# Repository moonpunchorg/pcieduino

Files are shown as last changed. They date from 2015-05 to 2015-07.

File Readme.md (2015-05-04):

PCIeDuino
=========

Arduino on a mini-PCIe express card.

Based design from Arduino and [SparkFun's Pro Micro 3.3V][promicro] board.

License
=======

To follow the licensing of the original Arduino modules,
all of this is shared under [CC BY-SA 3.0][cc] 2014 Moonpunch.org

[promicro]: https://www.sparkfun.com/products/12587 "Pro Micro - 3.3V/8MHz"
[cc]: https://creativecommons.org/licenses/by-sa/3.0/ "Creative Commons Attribution Share-Alike"

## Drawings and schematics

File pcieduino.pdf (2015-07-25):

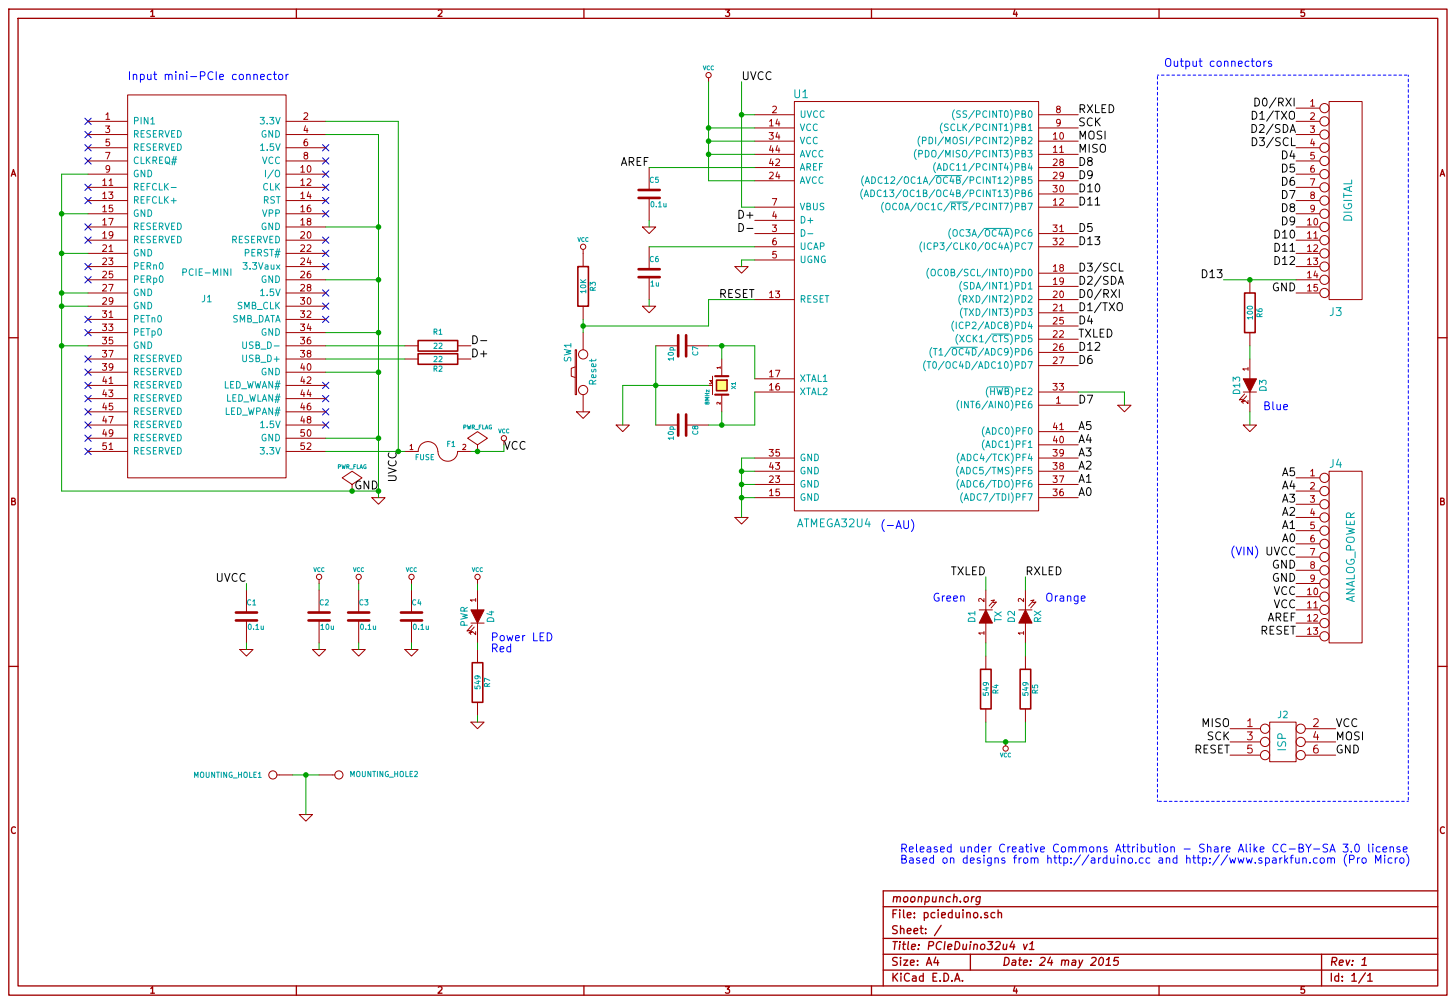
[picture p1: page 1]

Input mini-PCIe connector

Released under Creative Commons Attribution - Share Alike CC-BY-SA 3.0 license
Based on designs from http://arduino.cc and http://www.sparkfun.com (Pro Micro)

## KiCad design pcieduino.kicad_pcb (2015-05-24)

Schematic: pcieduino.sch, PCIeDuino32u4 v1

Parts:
C1, C3, C4, C5: 0.1u; SM0603_Capa; MouserPN 581-060316C104K
C2: 10u; Mouser PN 581-0805YD106K
C6: 1u; SM0603_Capa; MouserPN 581-0603YC105KAT2A
C7, C8: 10p; SM0603_Capa; MouserPN 581-06035A100J
D1: TX; LED-0603
D2: RX; LED-0603; MouserPN 720-LOL29KH2L124Z
D3: D13; LED-0603
D4: PWR; LED-0603; MouserPN 720-LSL29K-G1H2-1-Z
F1: FUSE; MouserPN 576-1206L110THYR
J1: PCIE-MINI; MODULE
J2: ISP
J3: DIGITAL
J4: ANALOG_POWER
MOUNTING_HOLE1, MOUNTING_HOLE2: CONN_1
R1, R2: 22; SM0603_Resistor; MouserPN 71-CRCW0603-22-E3
R3: 10K; SM0603_Resistor; MouserPN 71-CRCW0603-10K-E3
R4, R5, R7: 549; SM0603_Resistor; MouserPN 71-CRCW0603-549-E3
R6: 100; SM0603_Resistor; MouserPN 71-CRCW0603-100-E3
SW1: Reset; MouserPN 612-TL3313AF100QG
U1: ATMEGA32U4; TQFP44; MouserP# 556-ATMEGA32U4-AU
X1: 8MHz; SMDXTAL_50x32; MouserPN 815-ABM3B-8.0-10-1UT

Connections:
/A0: J4.6, U1.36
/A1: J4.5, U1.37
/A2: J4.4, U1.38
/A3: J4.3, U1.39
/A4: J4.2, U1.40
/A5: J4.1, U1.41
/AREF: C5.1, J4.12, U1.42
/D0/RXI: J3.1, U1.20
/D1/TXO: J3.2, U1.21
/D2/SDA: J3.3, U1.19
/D3/SCL: J3.4, U1.18
/D4: J3.5, U1.25
/D5: J3.6, U1.31
/D6: J3.7, U1.27
/D7: J3.8, U1.1
/D8: J3.9, U1.28
/D9: J3.10, U1.29
/D10: J3.11, U1.30
/D11: J3.12, U1.12
/D12: J3.13, U1.26
/D13: J3.14, R6.1, U1.32
/D+: R2.1, U1.4
/D-: R1.1, U1.3
/MISO: J2.1, U1.11
/MOSI: J2.4, U1.10
/RESET: J2.5, J4.13, R3.2, SW1.2, U1.13
/RXLED: D2.2 (K), U1.8
/SCK: J2.3, U1.9
/TXLED: D1.2 (K), U1.22
/UVCC: C1.1, F1.1, J1.2 (3.3V), J1.52 (3.3V), J4.7, U1.2, U1.7
GND: C1.2, C2.2, C3.2, C4.2, C5.2, C6.2, C7.2, C8.2, D3.2 (K), J1.4 (GND), J1.9 (GND), J1.15 (GND), J1.18 (GND), J1.21 (GND), J1.26 (GND), J1.27 (GND), J1.29 (GND), J1.34 (GND), J1.35 (GND), J1.40 (GND), J1.50 (GND), J2.6, J3.15, J4.8, J4.9, MOUNTING_HOLE1.1, MOUNTING_HOLE2.1, R7.2, SW1.1, U1.5, U1.15, U1.23, U1.33, U1.35, U1.43, X1.3 (case)
unnamed: J1.36 (USB_D-), R1.2
unnamed: J1.38 (USB_D+), R2.2
unnamed: C6.1, U1.6
unnamed: D4.2 (K), R7.1
unnamed: C8.1, U1.16, X1.2
unnamed: C7.1, U1.17, X1.1
unnamed: D3.1 (A), R6.2
unnamed: D1.1 (A), R4.1
unnamed: D2.1 (A), R5.1
VCC: C2.1, C3.1, C4.1, D4.1 (A), F1.2, J2.2, J4.10, J4.11, R3.1, R4.2, R5.2, U1.14, U1.24, U1.34, U1.44

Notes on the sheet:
Released under Creative Commons Attribution - Share Alike CC-BY-SA 3.0 license Based on designs from http://arduino.cc and http://www.sparkfun.com (Pro Micro)
Output connectors
Input mini-PCIe connector
Power LED Red
(VIN)
Green
Orange
Blue
(-AU)

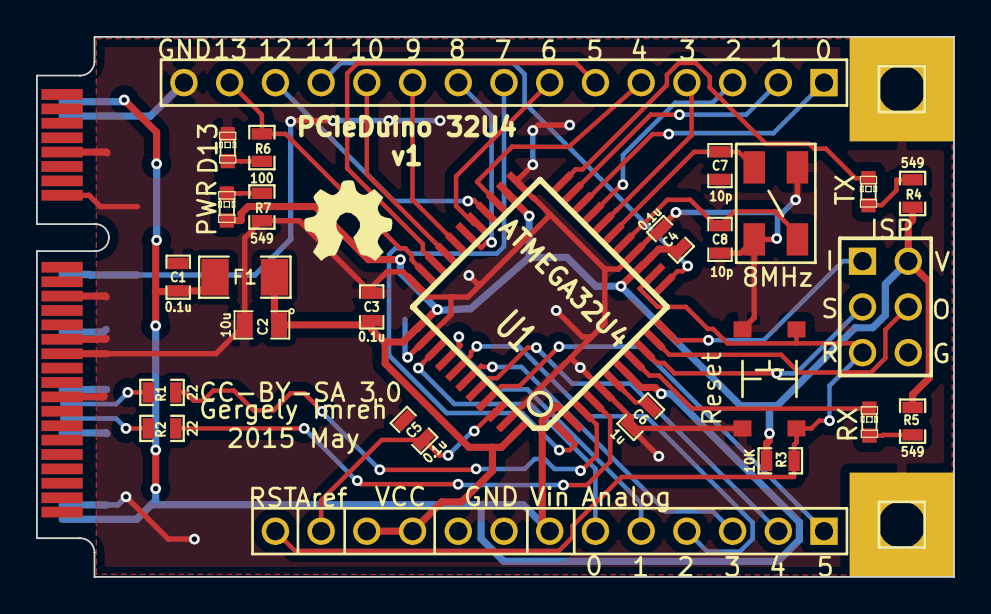
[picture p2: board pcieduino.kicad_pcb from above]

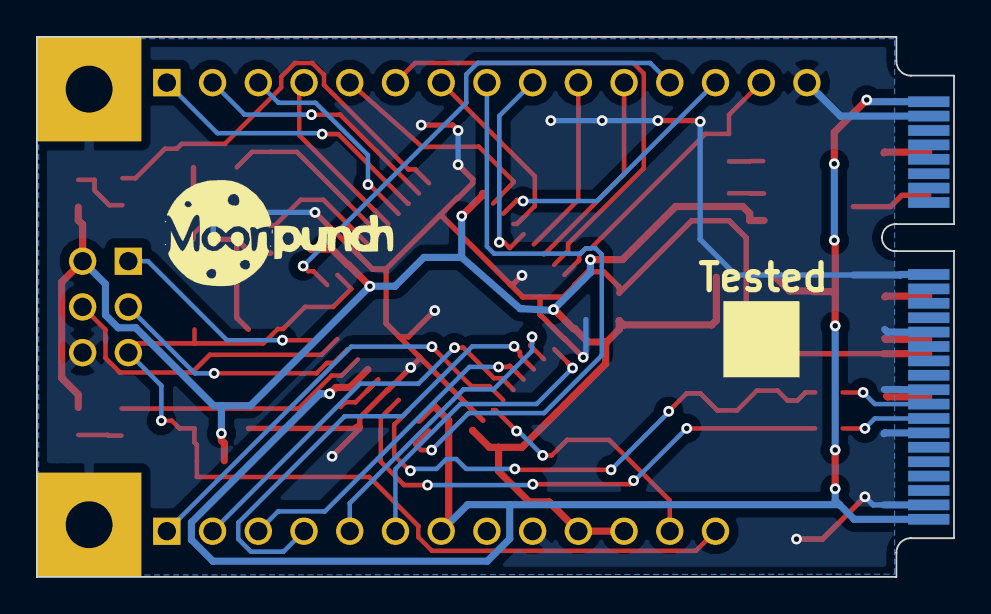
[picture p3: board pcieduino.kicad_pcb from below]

Board: 2 copper layers, 51.0 x 30.0 mm, 32 parts (2 on the bottom side), 41 nets.

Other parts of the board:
MOONPUNCH: LOGO
OSHW: LOGO; OSHW
TESTED: LOGO; SQUARE

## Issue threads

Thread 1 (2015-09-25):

Replace fuse

imrehg, 2015-09-25:
Replace fuse with lower trip current version. Had a few shorts in production, and would be better to protect the circuit with lower current setting.

Current version is 1.1A hold current, 2.2 trip current. That might be too high! Use a different one, looking at Littelfuse 1206L075TH, with hold current 0.75A, trip current 1.5A. The key feature to choose that is the hold current decreases as ambient temperature increases (see [docs](http://www.mouser.com/ds/2/240/Littelfuse_PTC_1206L-34409.pdf)), eg. at 60C ambient it's only 0.54A. The other part I was thinking about is a 0.5A hold current version, but at 60C it drops to 0.35A (and even at 40C it's 0.42A, which is too small.

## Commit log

2014-08-21 work in progress
    [pcieduino.sch]
2014-08-23 add recent more progress
    [pcieduino.sch]
2014-08-24 finished first draft of schematic
    [pcieduino.sch]
2014-08-28 update connections
    [pcieduino.sch]
2014-10-11 latest updates starting to work on the PCB
    [pcieduino.sch]
2014-12-28 work in progress (footprint libraries)
2015-01-01 add miniPCIe connector pins footprint to library
2015-01-01 pcb: work in progress
    [pcieduino.kicad_pcb]
2015-01-01 add footprint assignments
2015-01-03 add progress on 01/03
    Quick summary:
    * new crystal footprint
    * new switch footprint
    * combining digital pins
    * adding mounting holes
    ... and some small positioning changes
    [pcieduino.kicad_pcb, pcieduino.sch]
2015-01-03 more progress on 01/03
    [pcieduino.kicad_pcb, pcieduino.sch]
2015-01-04 add 01/04 changes
    summary:
    * redrawn the board starting from x=100.00, y=100.00 to have fix positioning
    * combine analog and power headers
    * remove RESET from power header because it already exists elsewhere
    * redraw fill zones with duplication
    [pcieduino.kicad_pcb, pcieduino.sch]
2015-01-05 progres on 01/05: mostly crystal work
    [pcieduino.kicad_pcb, pcieduino.sch]
2015-01-05 lock some components
    [pcieduino.kicad_pcb]
2015-05-01 ATmega32U4 version work in progress
    [pcieduino.sch]
2015-05-01 updates to the schematic (simplifications, labels, power LED
    [pcieduino.sch]
2015-05-02 work in progress: Mouser part numbers, new switch footprint, fixed footprint mixups
    [pcieduino.kicad_pcb, pcieduino.sch]
2015-05-03 work in progress, after autorouting and all connections
    [pcieduino.kicad_pcb, pcieduino.sch]
2015-05-04 PCIeDuino32U4v1 submitted for printing at Seeed
    [pcieduino.kicad_pcb]
2015-05-04 add gerbers
    [pcieduino-B_Cu.gbl, pcieduino-B_Mask.gbs, pcieduino-B_SilkS.gbo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]
2015-05-24 Updated version, ready to print
    * fixed XTAL footprint
    * changed 10u bypass footprint
    * general layout improvements
    * added Moonpunch logo
    [pcieduino-B_Cu.gbl, pcieduino-B_Mask.gbs, pcieduino-B_SilkS.gbo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]
2015-07-25 add PDF export of schematics
